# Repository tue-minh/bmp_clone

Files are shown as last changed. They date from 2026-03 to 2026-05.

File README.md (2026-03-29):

# 🚀 How to Load Firmware into STM32F103C8T6 (Bluepill)

This guide provides detailed instructions for loading Blackmagic firmware onto the Bluepill board using either an ST-Link or Black Magic Probe (BMP).

<table align="center">
  <tr>
    <th>Front</th>
    <th>Back</th>
  </tr>
  <tr>
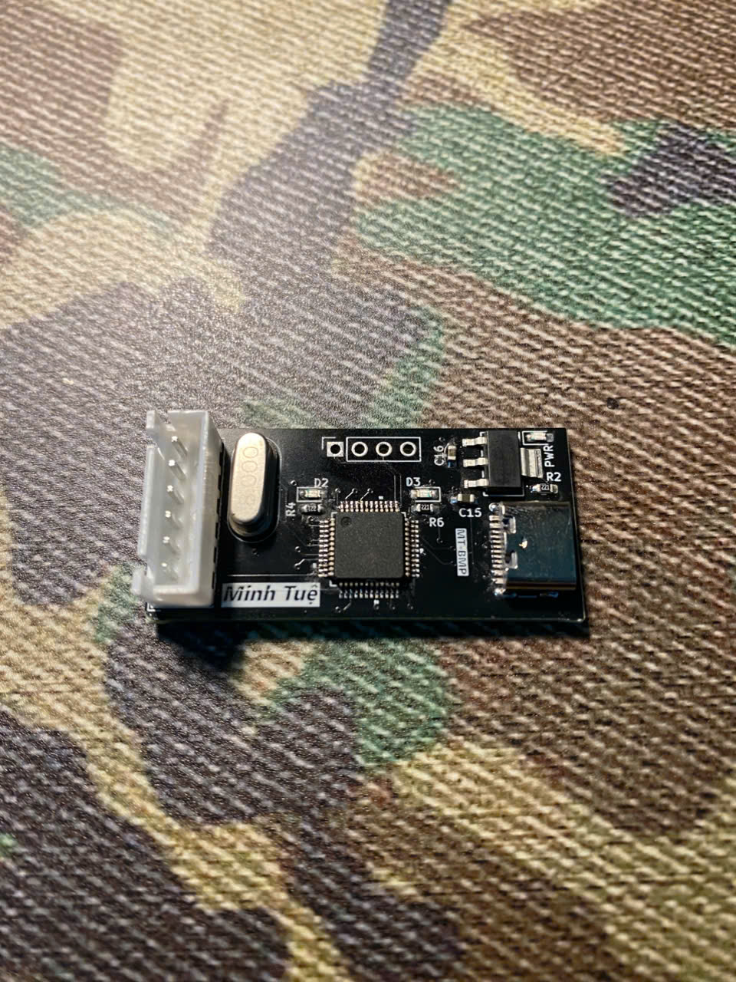
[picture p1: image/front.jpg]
    <td></td>
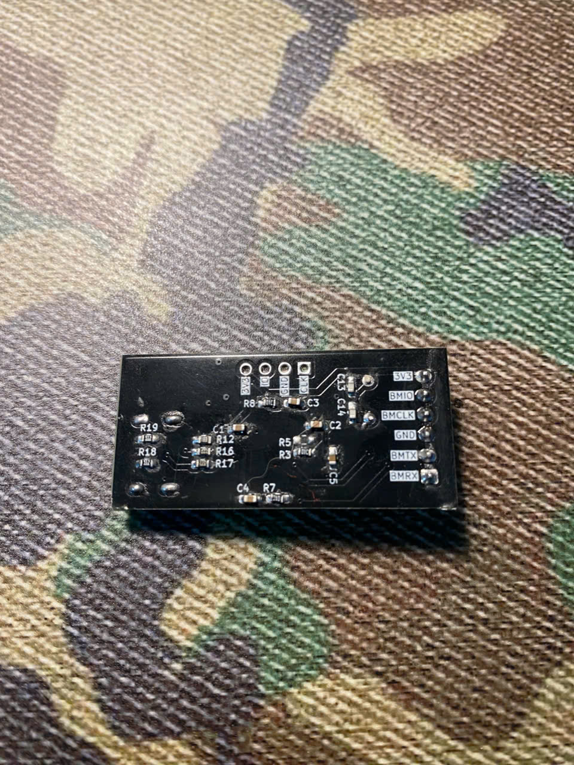
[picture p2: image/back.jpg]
    <td></td>
  </tr>
</table>

---

## 📂 1. Prepare the Firmware Files
Locate the following files in your build directory:
- `.../blackmagic-firmware-v1.10.2/bluepill/blackmagic_dfu-bluepill.elf`
- `.../blackmagic-firmware-v1.10.2/bluepill/blackmagic-bluepill.elf`

---

## 🛠️ 2. Install GDB Tool
Open **PowerShell** or **Terminal** and run the following command:
```bash
arm-none-eabi-gdb
```

> **Tip:**
> If GDB is not installed, you can use the version included with PlatformIO by running:
> ```powershell
> # Check the path
> dir $env:USERPROFILE\.platformio\packages\toolchain-gccarmnoneeabi\bin
>
> # Run GDB directly
> & "$env:USERPROFILE\.platformio\packages\toolchain-gccarmnoneeabi\bin\arm-none-eabi-gdb.exe"
> ```

---

## ⚡ 3. Flash the Firmware

Choose your preferred flashing method:

### 🔹 Method A: Using ST-LINK
Use the `st-flash` tool to flash the firmware via the SWD interface:
```bash
# Erase old memory
st-flash erase

# Flash the DFU Bootloader (at address 0x8000000)
st-flash --flash=0x20000 write .../blackmagic-firmware-v1.10.2/bluepill/blackmagic_dfu-bluepill.elf 0x8000000

# Flash the main firmware (at address 0x8002000) and reset
st-flash --flash=0x20000 --reset write .../blackmagic-firmware-v1.10.2/bluepill/blackmagic-bluepill.elf 0x8002000
```

### 🔹 Method B: Using Black Magic Probe (BMP)
Run GDB and execute the following commands:
```bash
# Connect to BMP (replace COMx with the appropriate port)
target extended-remote COMx           # For Windows
target extended-remote /dev/tty*      # For Linux

monitor swdp_scan
attach 1
monitor halt
monitor erase_mass

# Flash the DFU Bootloader
file .../blackmagic-firmware-v1.10.2/bluepill/blackmagic_dfu-bluepill.elf
load

# Flash the main firmware
file .../blackmagic-firmware-v1.10.2/bluepill/blackmagic-bluepill.elf
load

monitor reset
continue
```

---

## 🧠 Important Notes

### Flash Memory Addresses
- The `.elf` files usually contain the address information, so manual specification is often unnecessary.
- STM32F103 Flash starts at `0x08000000`.
  - **DFU Bootloader:** Typically occupies the first 8KB (`0x08000000 → 0x08002000`).

### ✅ Result
After successfully flashing, disconnect and reconnect the board to your PC via USB. If successful, your computer will detect two Virtual COM ports:
1. **GDB Port**
2. **UART Port**

Congratulations! Enjoy your new Blackmagic Probe! 🎉

---

## 📞 Quick Troubleshooting

| **Error** | **Cause** | **Solution** |
|---|---|---|
| `unknown architecture "arm"` | Incorrect GDB version | Use the correct `arm-none-eabi-gdb`. |
| `load failed` | Memory not erased | Run `monitor erase_mass` before loading. |
| `attach` error | Physical connection issue  | Check the `monitor swdp_scan` command. |
| Target not detected | Loose or incorrect SWD wires | Verify SWDIO and SWCLK connections.  |

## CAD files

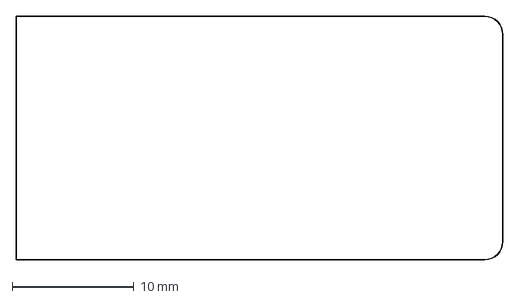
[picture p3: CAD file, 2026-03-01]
hardware/Layout.dxf
40.0 x 20.0 mm

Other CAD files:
hardware/Layout.dwg

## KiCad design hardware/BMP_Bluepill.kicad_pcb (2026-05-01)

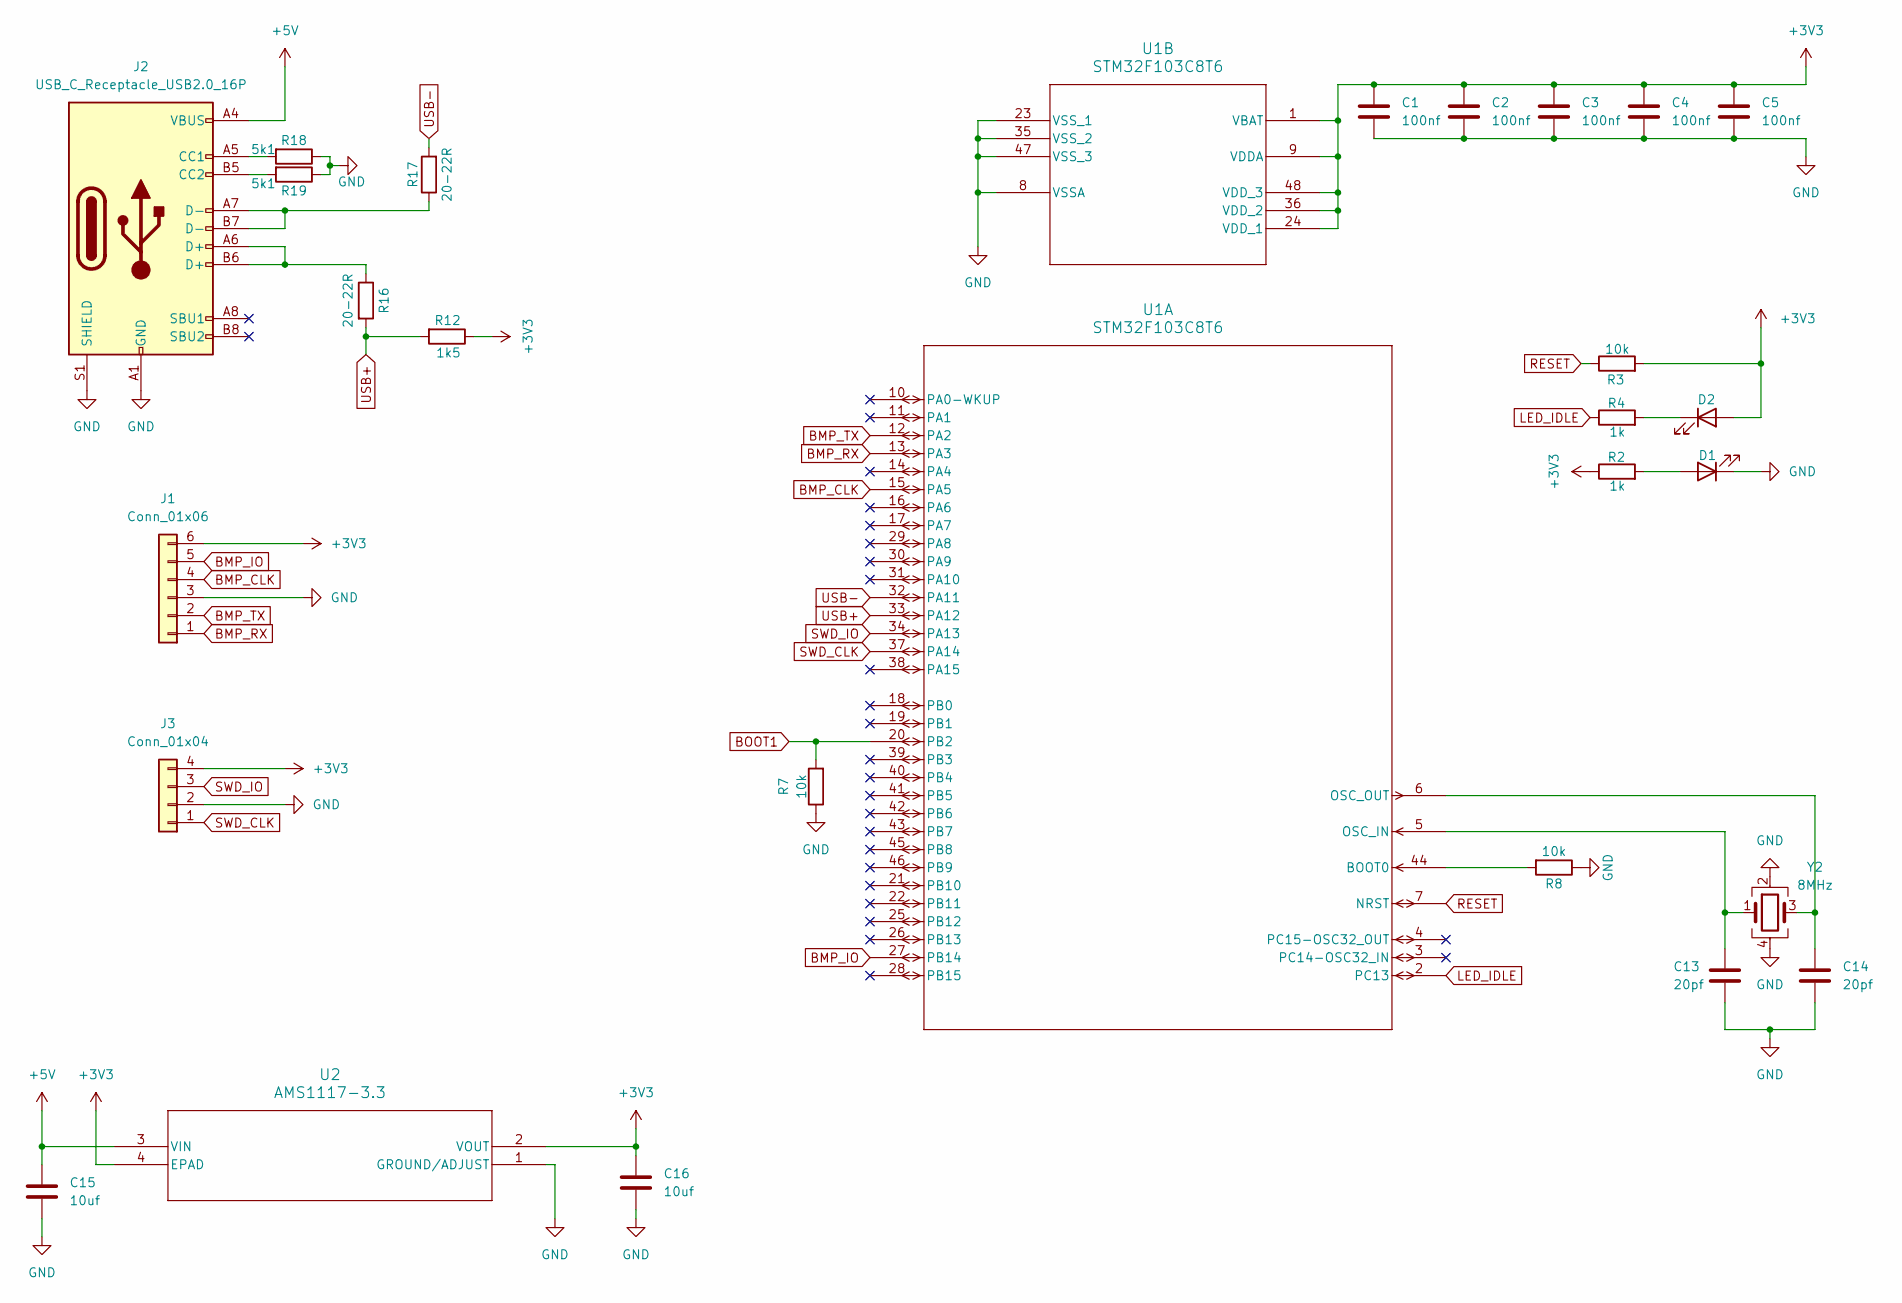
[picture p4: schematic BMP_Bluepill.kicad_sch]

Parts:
C1, C2, C3, C4, C5: 100nf; C_0603_1608Metric_Pad1.08x0.95mm_HandSolder
C13, C14: 20pf; C_0603_1608Metric_Pad1.08x0.95mm_HandSolder
C15, C16: 10uf; C_0603_1608Metric_Pad1.08x0.95mm_HandSolder
D1, D2: LED; LED_0603_1608Metric_Pad1.05x0.95mm_HandSolder
J1: Conn_01x06; JST_XH_B6B-XH-A_1x06_P2.50mm_Vertical
J2: USB_C_Receptacle_USB2.0_16P; USB_C_Receptacle_GCT_USB4105-xx-A_16P_TopMnt_Horizontal
J3: Conn_01x04; PinSocket_1x04_P2.54mm_Vertical
R2, R4: 1k; R_0603_1608Metric_Pad0.98x0.95mm_HandSolder
R3, R7, R8: 10k; R_0603_1608Metric_Pad0.98x0.95mm_HandSolder
R12: 1k5; R_0603_1608Metric_Pad0.98x0.95mm_HandSolder
R16, R17: 20-22R; R_0603_1608Metric_Pad0.98x0.95mm_HandSolder
R18, R19: 5k1; R_0603_1608Metric_Pad0.98x0.95mm_HandSolder
U1: STM32F103C8T6; LQFP48_STM
U2: AMS1117-3.3; SOT_AMS_ADS
Y2: 8MHz; Crystal_SMD_5032-4Pin_5.0x3.2mm

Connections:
+3V3: C1.1, C2.1, C3.1, C4.1, C5.1, C16.1, D2.2 (A), J1.6, J3.4, R2.1, R3.2, R12.1, U1.1 (VBAT), U1.9 (VDDA), U1.24 (VDD_1), U1.36 (VDD_2), U1.48 (VDD_3), U2.2 (VOUT), U2.4 (EPAD)
+5V: C15.1, J2.A4 (VBUS), J2.A9 (VBUS), J2.B4 (VBUS), J2.B9 (VBUS), U2.3 (VIN)
BMP_CLK: J1.4, U1.15 (PA5)
BMP_IO: J1.5, U1.27 (PB14)
BMP_RX: J1.1, U1.13 (PA3)
BMP_TX: J1.2, U1.12 (PA2)
BOOT1: R7.2, U1.20 (PB2)
GND: C1.2, C2.2, C3.2, C4.2, C5.2, C13.2, C14.2, C15.2, C16.2, D1.1 (K), J1.3, J2.A1 (GND), J2.A12 (GND), J2.B1 (GND), J2.B12 (GND), J2.S1 (SHIELD), J3.2, R7.1, R8.1, R18.1, R19.1, U1.8 (VSSA), U1.23 (VSS_1), U1.35 (VSS_2), U1.47 (VSS_3), U2.1 (GROUND/ADJUST), Y2.2, Y2.4
LED_IDLE: R4.1, U1.2 (PC13)
unnamed: D1.2 (A), R2.2
unnamed: D2.1 (K), R4.2
unnamed: J2.A5 (CC1), R18.2
unnamed: J2.B5 (CC2), R19.2
unnamed: J2.A6 (D+), J2.B6 (D+), R16.1
unnamed: J2.A7 (D-), J2.B7 (D-), R17.1
unnamed: R8.2, U1.44 (BOOT0)
unnamed: C13.1, U1.5 (OSC_IN), Y2.1
unnamed: C14.1, U1.6 (OSC_OUT), Y2.3
RESET: R3.1, U1.7 (NRST)
SWD_CLK: J3.1, U1.37 (PA14)
SWD_IO: J3.3, U1.34 (PA13)
USB+: R12.2, R16.2, U1.33 (PA12)
USB-: R17.2, U1.32 (PA11)

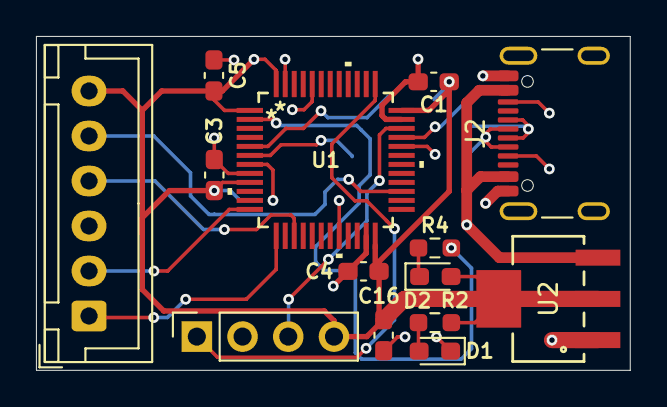
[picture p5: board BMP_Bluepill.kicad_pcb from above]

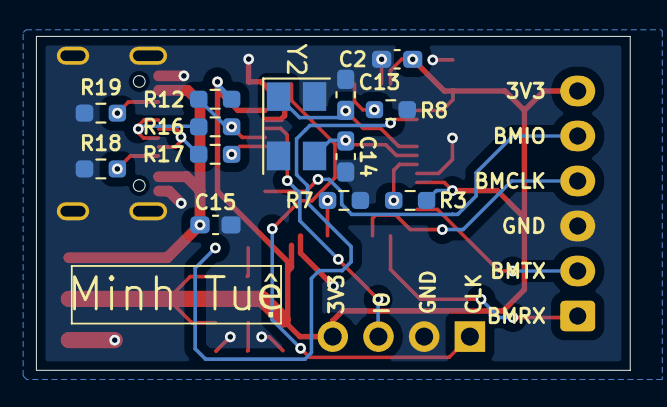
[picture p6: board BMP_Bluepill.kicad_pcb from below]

Board: 2 copper layers, 33.0 x 18.5 mm, 27 parts (13 on the bottom side), 23 nets.

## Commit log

2026-03-03 fix layout
    [BMP_Bluepill-B_Cu.gbr, BMP_Bluepill-B_Mask.gbr, BMP_Bluepill-B_Paste.gbr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]
2026-03-29 relocate file
    [BMP_Bluepill.kicad_pcb, BMP_Bluepill.kicad_sch, Layout.dwg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]
2026-05-01 update layout
    [BMP_Bluepill.kicad_pcb, BMP_Bluepill.kicad_sch, freerouting.dsn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]
